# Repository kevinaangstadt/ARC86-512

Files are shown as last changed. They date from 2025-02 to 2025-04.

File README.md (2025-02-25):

# ARC86-512 Computer
## Introduction
This is a simple, but complete computer built around the 80C88 processor. In
addition to the processor, the computer has:
- 512KB of RAM
- 32KB of ROM
- 1 16C550 UART
- 1 8255 PIO
- 1 8253 PIT
- 1 8259 PIC
- CompactFlash interface
- 8Ω speaker
- 16x2 character LCD

## Hardware

Hardware designs are available in the `hardware` directory. The computer is
designed to be built on a breadboard.

The hardware is released under the [CERN Open Hardware Licence Version 2 - Permissive](hardware/LICENSE.txt).

## Software

Software is available in the `software` directory. The software is written in
assembly language and is designed to be built with the [NASM
assembler](https://www.nasm.us/).

C code is written to be compiled [Bruce's C Compiler
(bcc)](https://github.com/lkundrak/dev86).

The software is released under the [BSD 3-Clause License](software/LICENSE.txt).

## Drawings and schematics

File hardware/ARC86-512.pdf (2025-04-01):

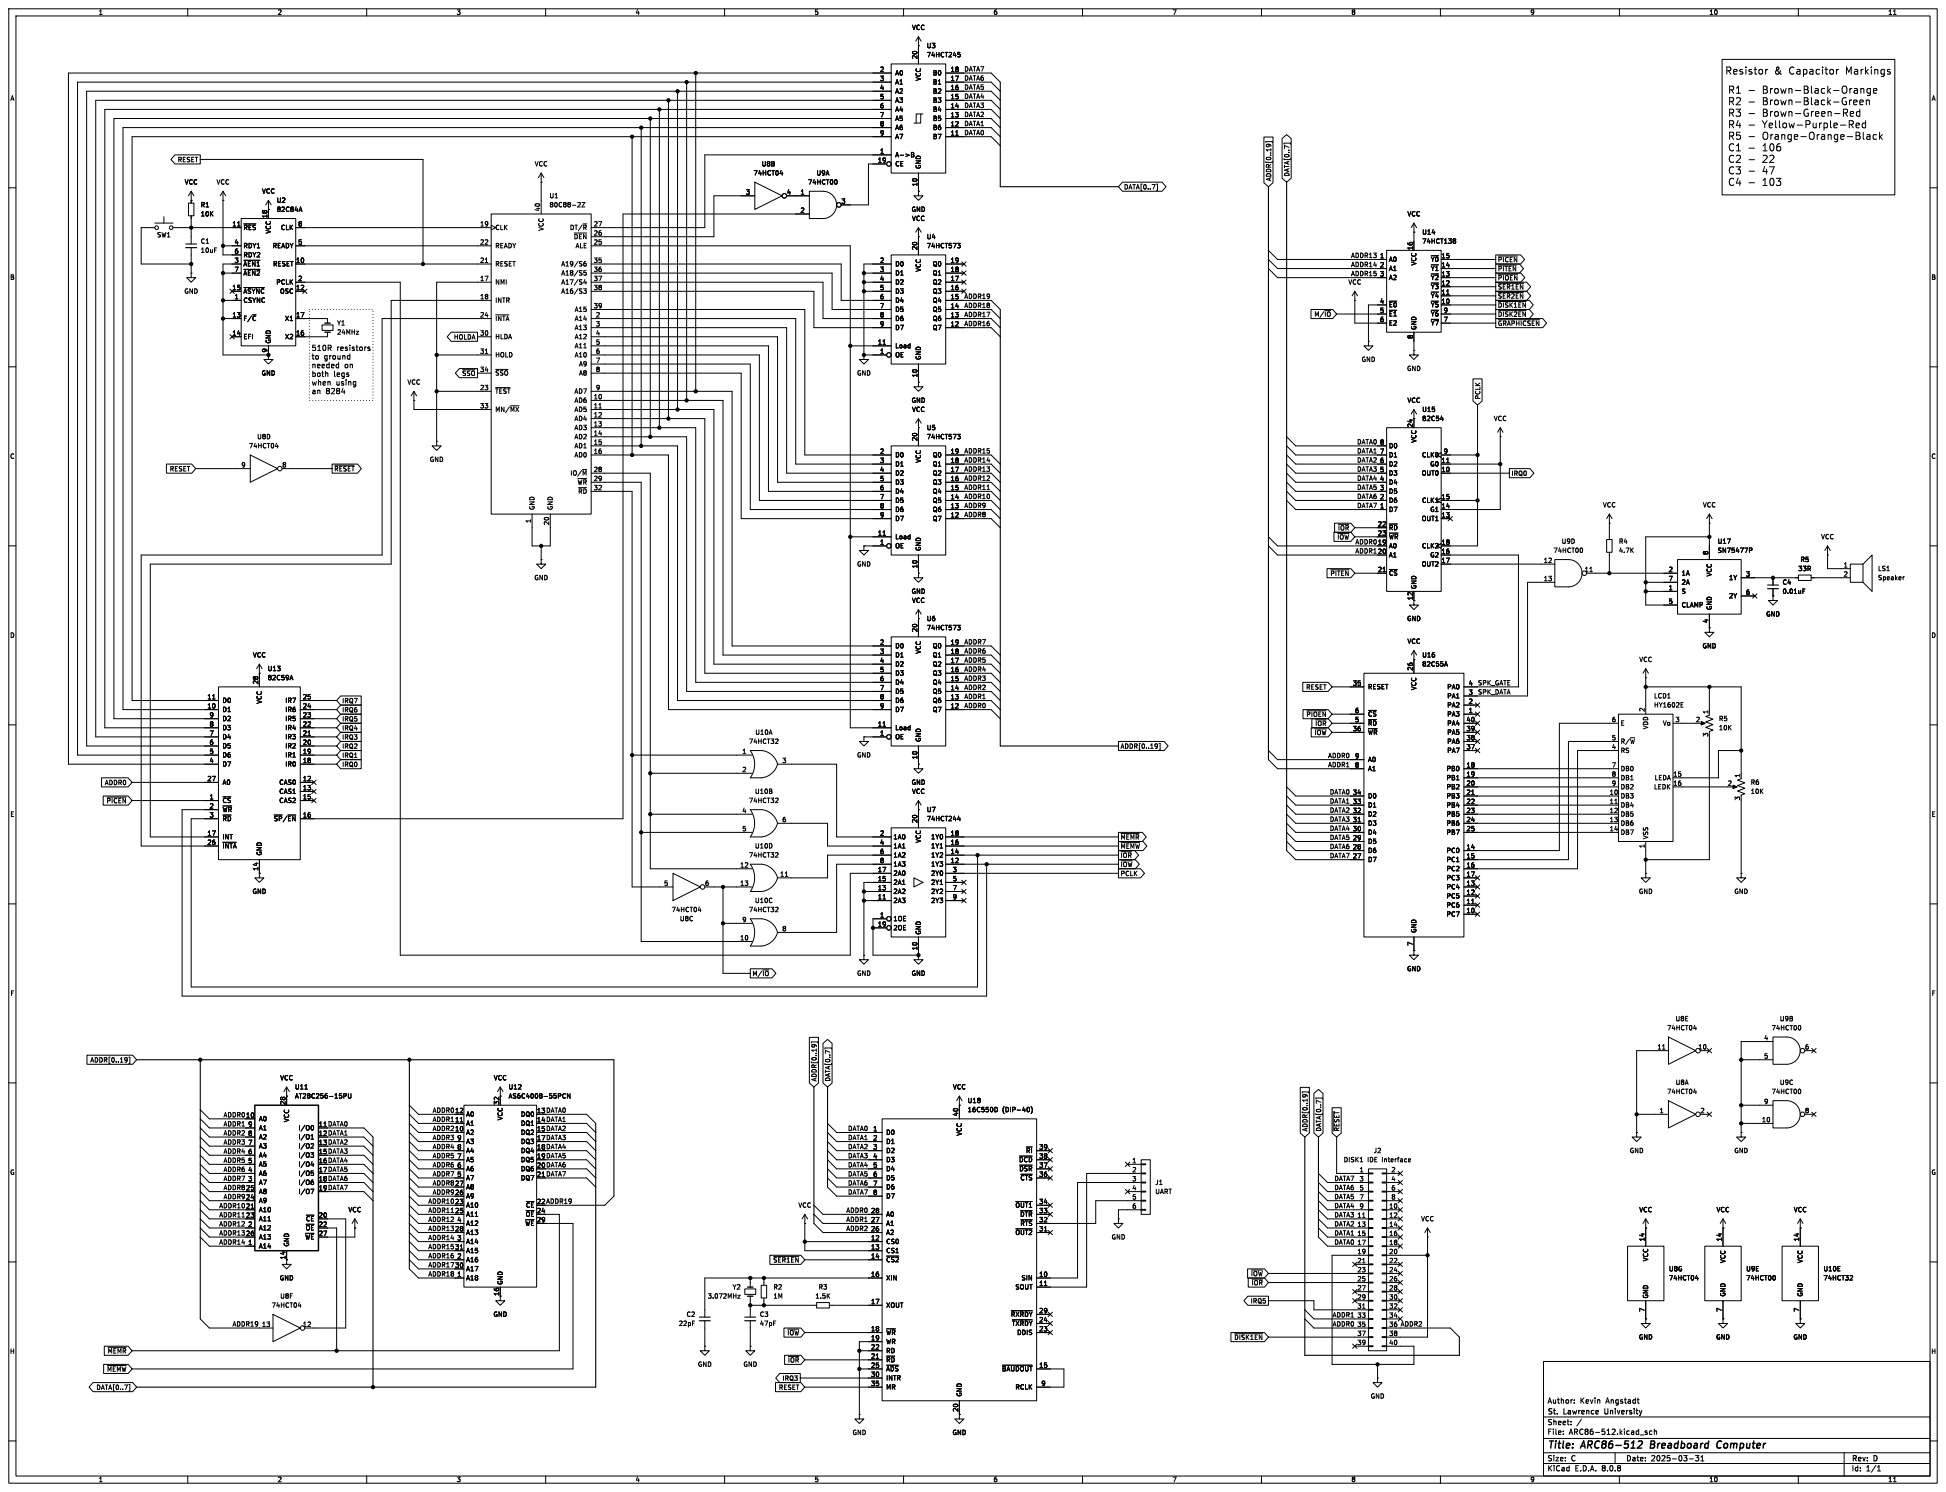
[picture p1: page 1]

510R resistors
to ground
needed on
both legs when using

ADDR[0..19] ~{MEMR} ~{MEMW} ~{IOW} PCLK

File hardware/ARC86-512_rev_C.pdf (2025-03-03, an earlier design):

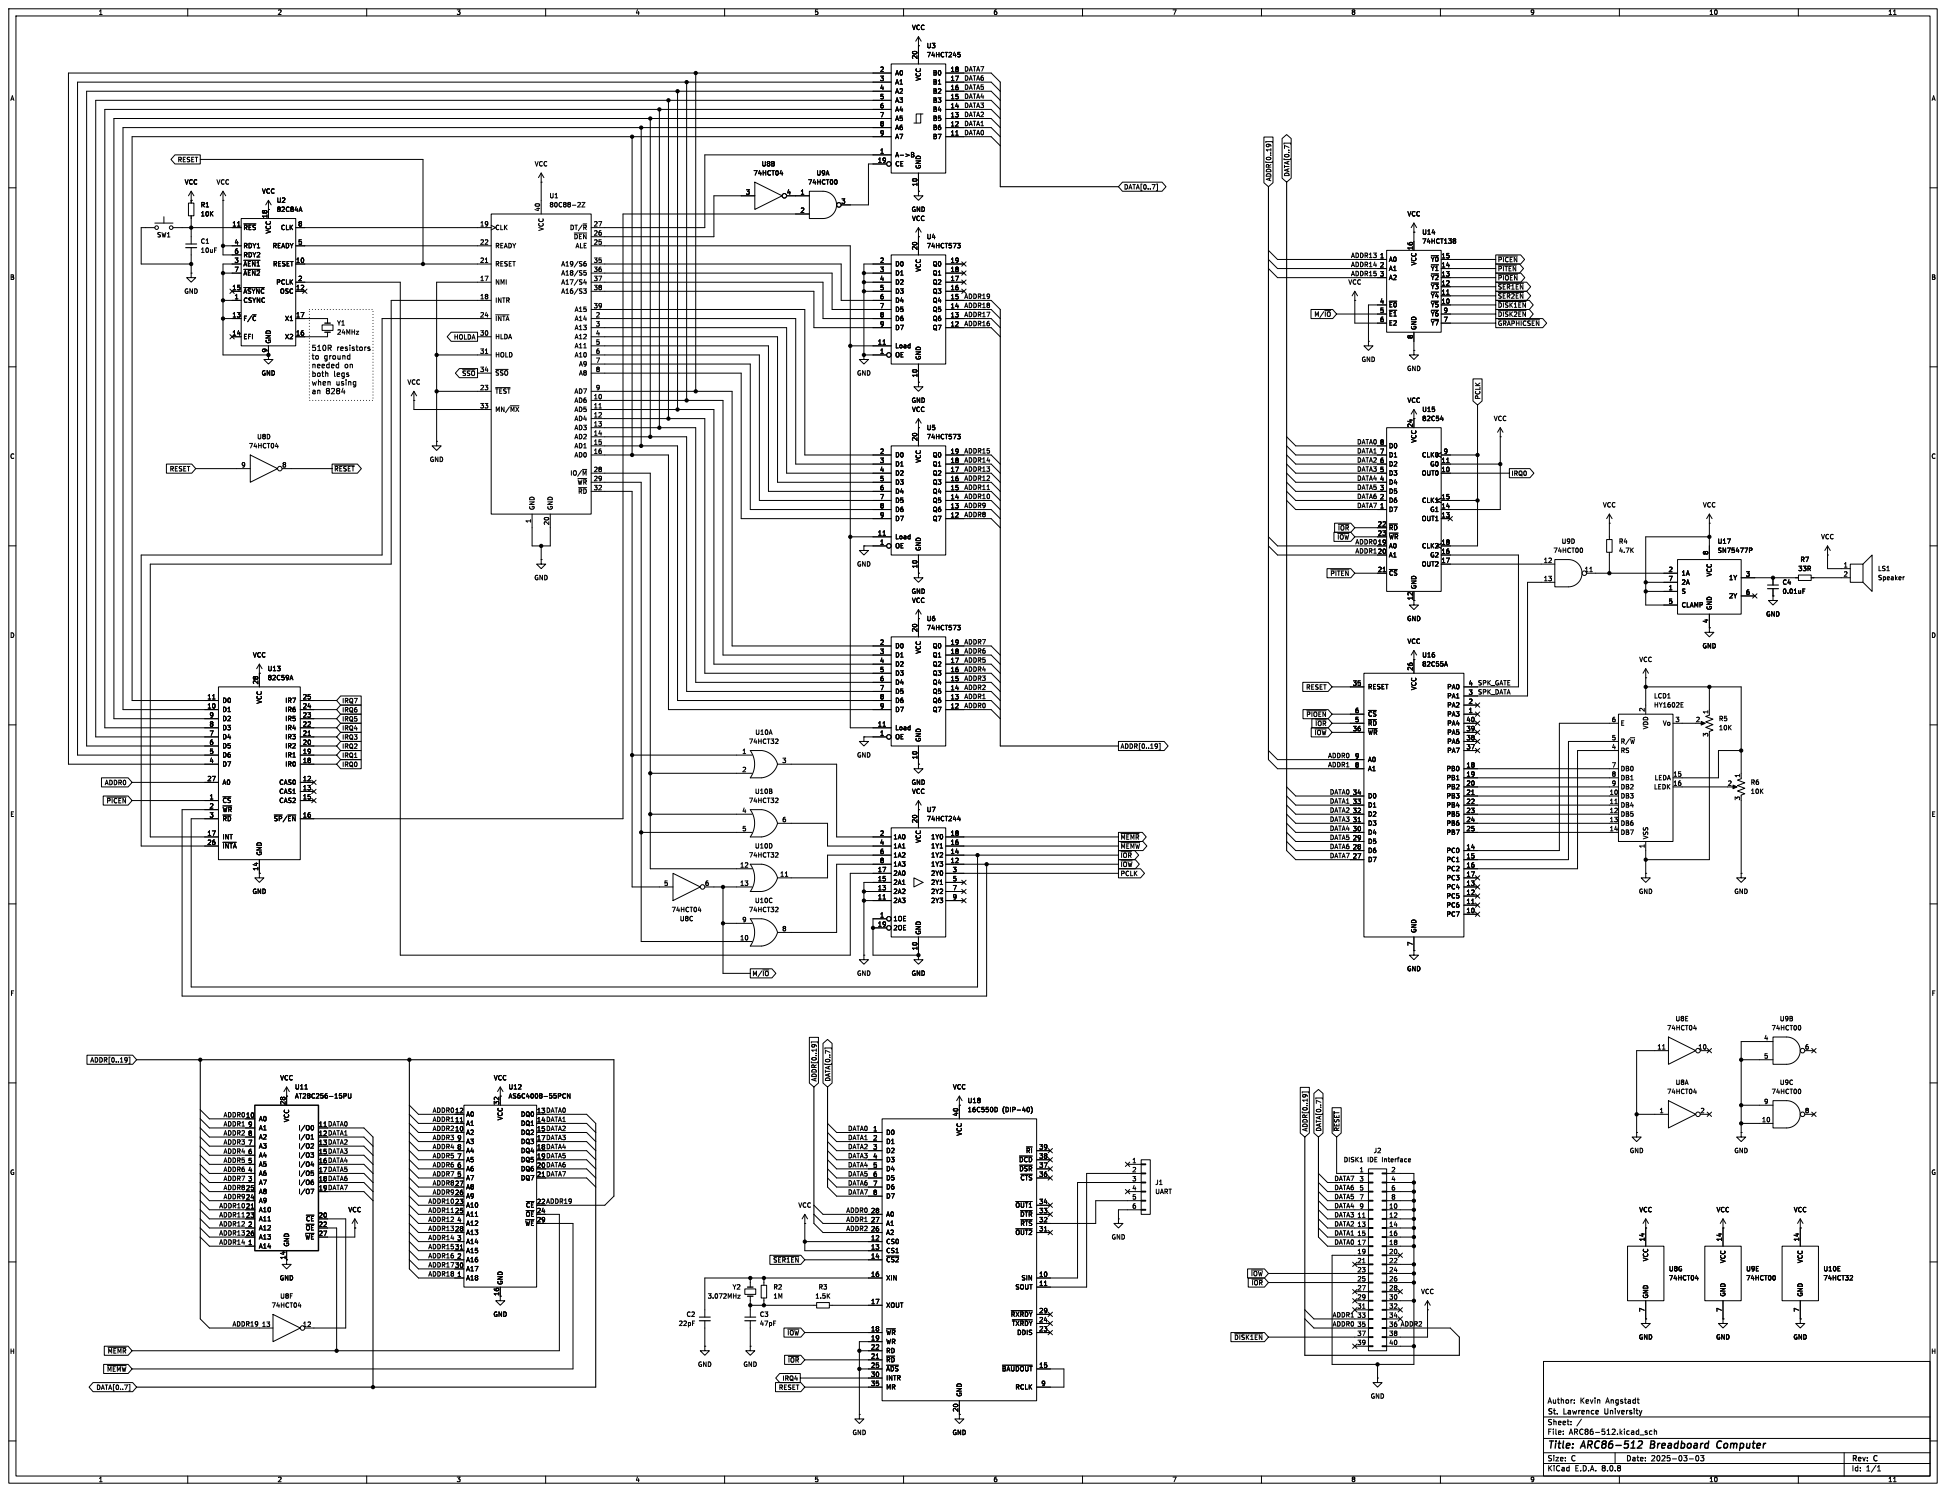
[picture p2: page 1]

~{SER2EN} ~{PITEN} ~{DISK2EN} ~{GRAPHICSEN} ~{SER1EN} ~{DISK1EN} ~{PICEN} ~{PIOEN} M/~{IO} ADDR[0..19] DATA[0..7]

~{IOW} ~{IOR} ~{PIOEN} RESET DATA[0..7]

~{MEMR} ~{IOR} ADDR[0..19] PCLK

74HCT04 VCC 14 GND 7 VCC GND

74HCT32 VCC 14 GND 7 VCC GND

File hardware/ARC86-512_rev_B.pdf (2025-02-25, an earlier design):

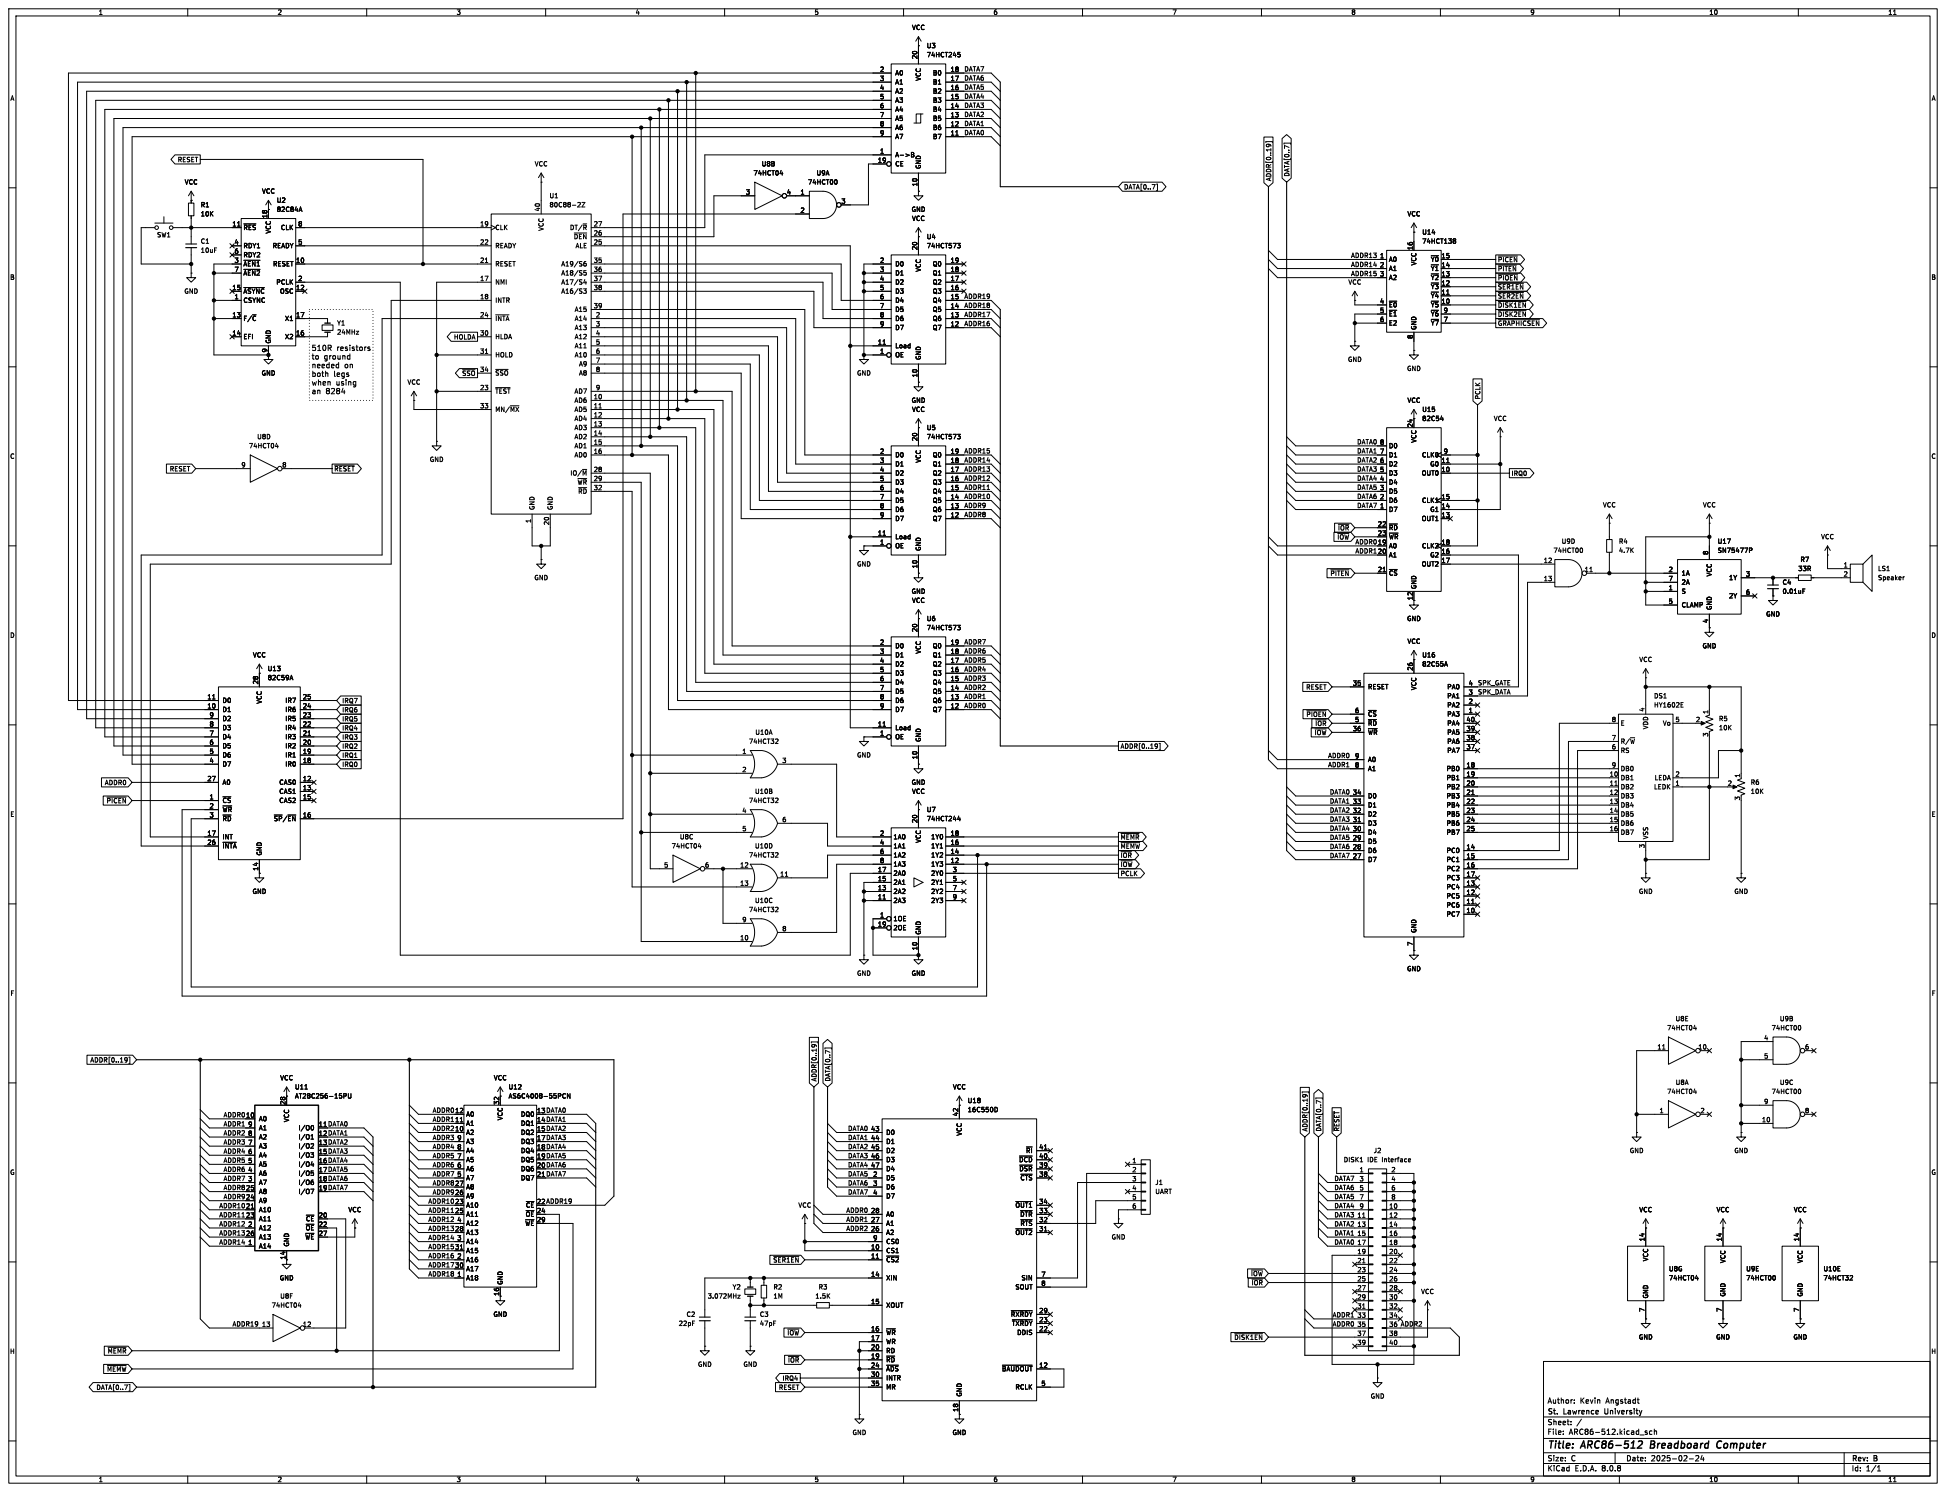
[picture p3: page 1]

to ground
needed on
both legs when using

~{PIOEN} ~{IOW} RESET ADDR[0..19] ~{IOR} ~{MEMW} ~{IOW} ~{MEMR}

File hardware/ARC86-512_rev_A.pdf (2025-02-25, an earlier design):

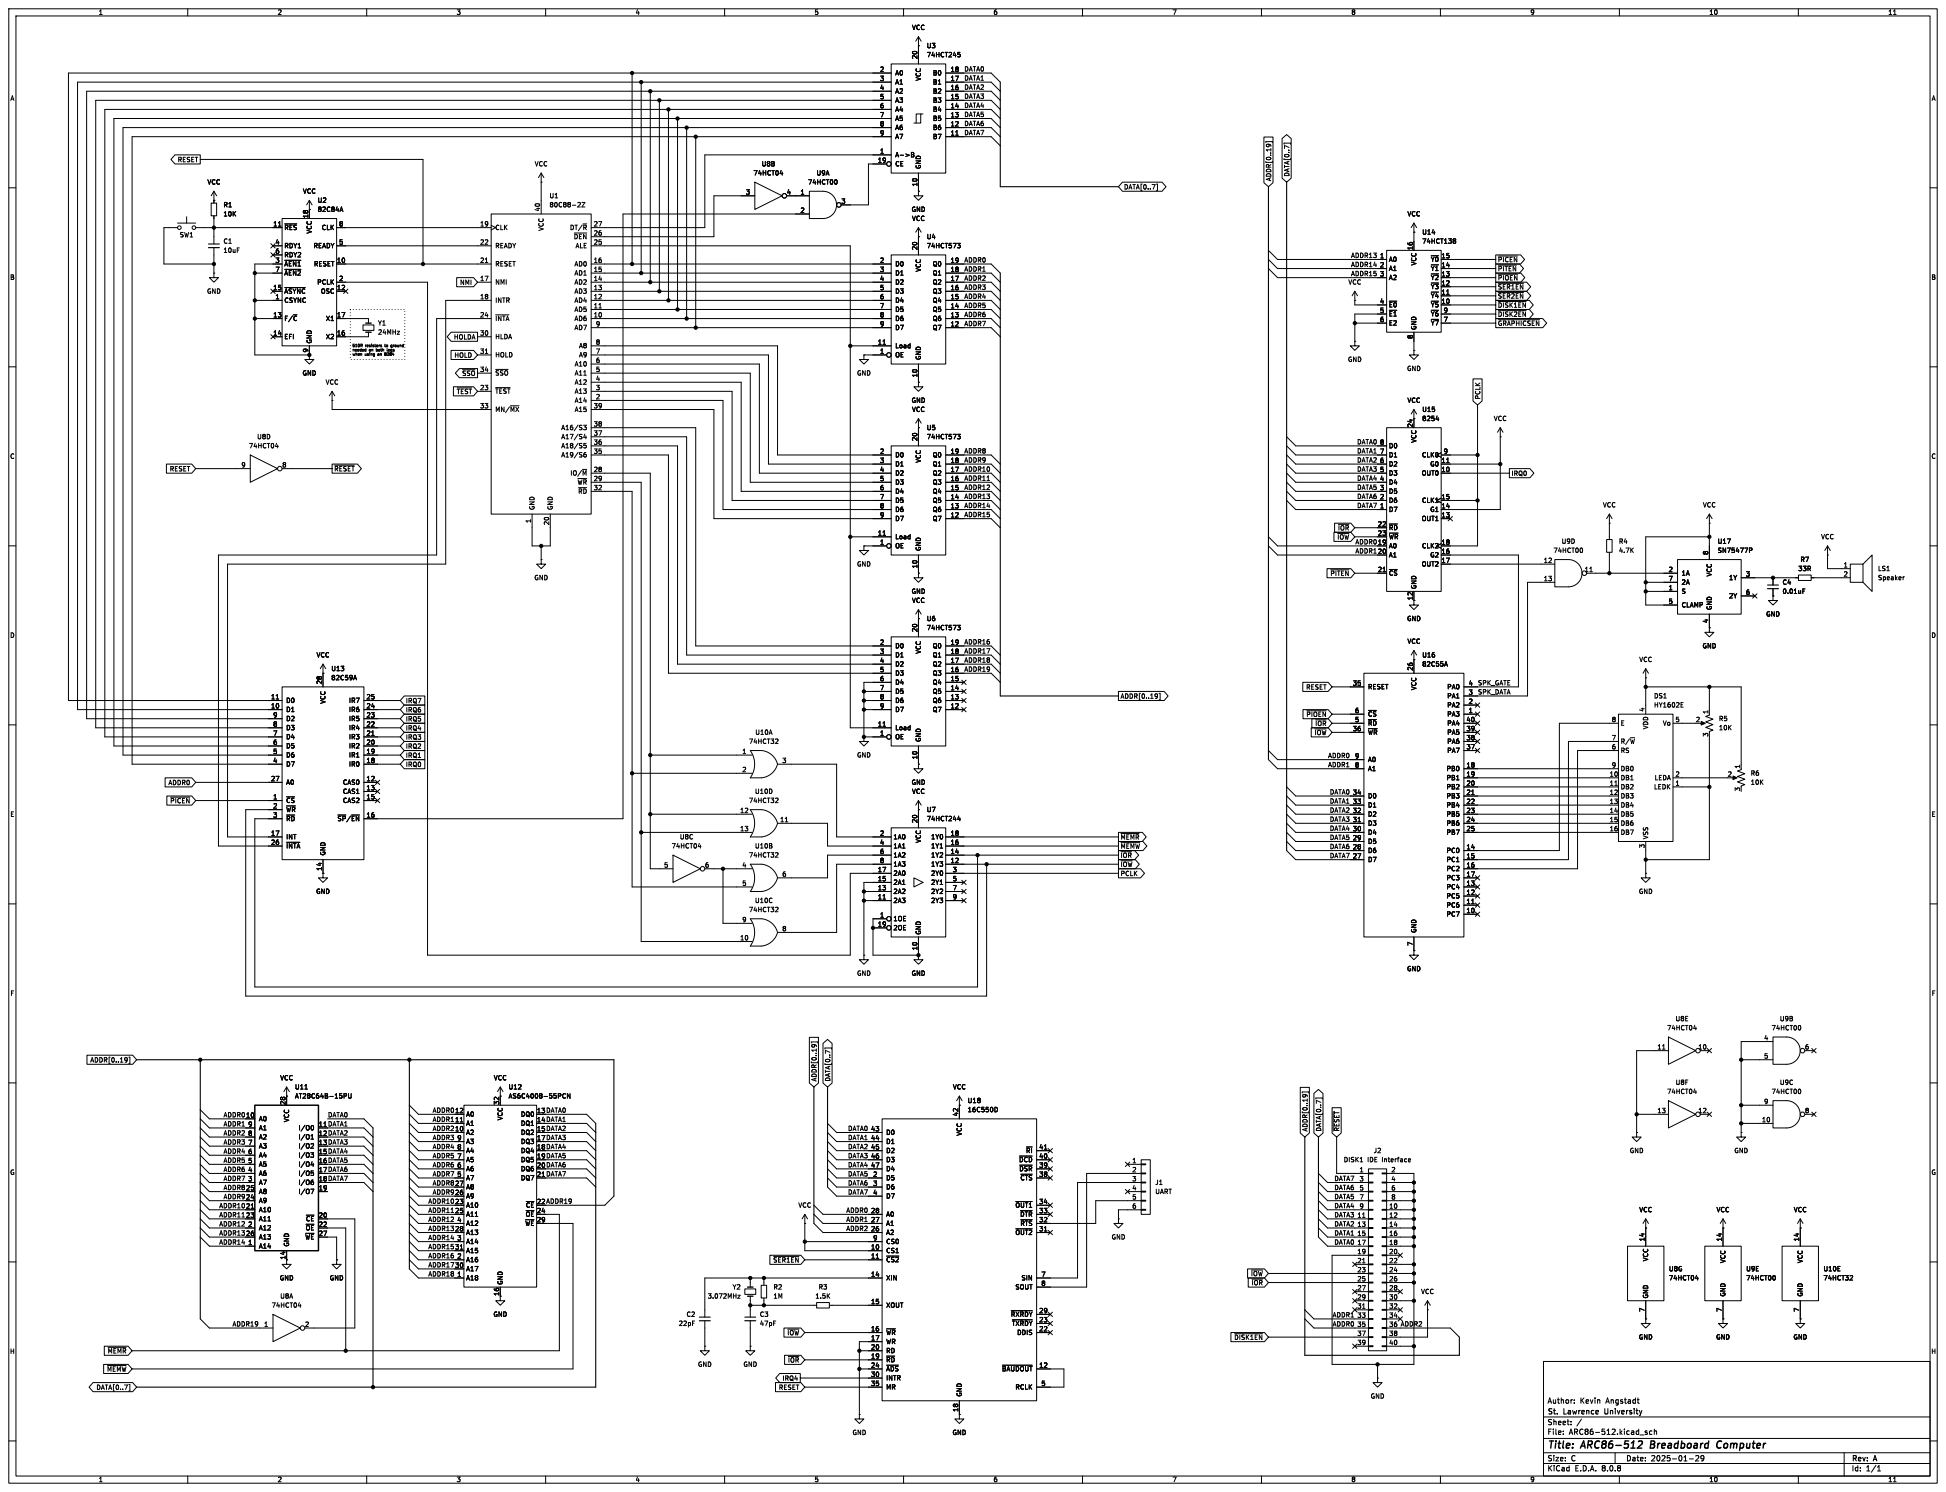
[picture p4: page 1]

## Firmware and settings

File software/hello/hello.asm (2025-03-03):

; set up the PIO Port B for output
; Configure the LCD for 8-bit mode

; NOTE: the PIO lives at IO port 0x4000
; address 0x00 PORT A
; address 0x01 PORT B
; address 0x02 PORT C
; address 0x03 Control Word

E equ 0x01
RS equ 0x04
RW equ 0x02

PORTA equ 0x4000
PORTB equ 0x4001
PORTC equ 0x4002
CTRL equ 0x4003

; the upper ROM chip starts at address 0xFE000
org 0xF8000

;;;;;;;;;;;;;;;;;;;;;;;;;;;;;;;;;;;;;;;;;;;;;;;;;;;;;;;;;;;;;;;;;;;;;;;;;;;;;;;;
; Initialize the LCD                                                           ;
;;;;;;;;;;;;;;;;;;;;;;;;;;;;;;;;;;;;;;;;;;;;;;;;;;;;;;;;;;;;;;;;;;;;;;;;;;;;;;;;

  ; set up GROUP A/B for MODE 0 output
  mov al, 0b10000000
  mov dx, CTRL
  out dx, al

  ; See the LCD datasheet for the initialization sequence
  ; Figure 23 on page 45 of the HD44780U datasheet for 8-Bit Interface Initialization

  ; busy wait for 40ms to allow the LCD to power up
  ; at 8Mhz, 1 cycle is 125ns meaning we need to busy wait for 320,000 cycles
  ; 320,000 cycles / 4 cycles per loop = 80,000 loops
  mov cx, 12000  ; 40000 loops
delay_loop1:
  nop            ; 4 cycle
  nop            ; 4 cycle
  nop            ; 4 cycle
  loop delay_loop1 ; 17 cycles to decrement and jump if not zero

  ; initialize with 8-bit mode with 3 commands 0x00110000
  mov al, 0b00110000
  mov dx, PORTB
  out dx, al
  ; clear RS/RW/E bits
  mov al, 0
  mov dx, PORTC
  out dx, al
  ; set E bit to send instruction
  mov al, E
  out dx, al
  ; clear RS/RW/E bits
  mov al, 0
  out dx, al

  ; wait for the LCD to process the instruction (more than 4.1ms)
  ; at 8Mhz, 1 cycle is 125ns meaning we need to busy wait for at least 32,800 cycles
  ; we will busy wait for 40,000 cycles
  mov cx, 1200  ; 10000 loops
delay_loop2:
  nop            ; 4 cycle
  nop            ; 4 cycle
  nop            ; 4 cycle
  loop delay_loop2 ; 17 cycles

  ; initialize a second time with 8-bit mode with 3 commands 0x00110000
  mov al, 0b00110000
  mov dx, PORTB
  out dx, al
  ; clear RS/RW/E bits
  mov al, 0
  mov dx, PORTC
  out dx, al
  ; set E bit to send instruction
  mov al, E
  out dx, al
  ; clear RS/RW/E bits
  mov al, 0
  out dx, al

  ; wait for the LCD to process the instruction (more than 100us)
  ; at 8Mhz, 1 cycle is 125ns meaning we need to busy wait for at least 800 cycles
  ; we will busy wait for 1000 cycles
  mov cx, 35    ; 34 loops
delay_loop3:
  nop            ; 4 cycle
  nop            ; 4 cycle
  nop            ; 4 cycle
  loop delay_loop3 ; 17 cycles

  ; initialize a third and final time time with 8-bit mode with 3 commands 0x00110000
  mov al, 0b00110000
  mov dx, PORTB
  out dx, al
  ; clear RS/RW/E bits
  mov al, 0
  mov dx, PORTC
  out dx, al
  ; set E bit to send instruction
  mov al, E
  out dx, al
  ; clear RS/RW/E bits
  mov al, 0
  out dx, al

  ; wait for the LCD to process the instruction
  ; set PORT B to input
  mov al, 0b10000010
  mov dx, CTRL
  out dx, al
wait6:
  mov al, RW
  mov dx, PORTC
  out dx, al
  ; set E bit to send instruction
  mov al, E | RW
  out dx, al
  ; read the busy flag
  mov dx, PORTB
  in al, dx
  and al, 0x80
  jne wait6
  mov al, 0
  mov dx, PORTC
  out dx, al
  ; set PORT B back to output
  mov al, 0b10000000
  mov dx, CTRL
  out dx, al

;;;;;;;;;;;;;;;;;;;;;;;;;;;;;;;;;;;;;;;;;;;;;;;;;;;;;;;;;;;;;;;;;;;;;;;;;;;;;;;;
; Set up the LCD with our desired settings                                     ;
;;;;;;;;;;;;;;;;;;;;;;;;;;;;;;;;;;;;;;;;;;;;;;;;;;;;;;;;;;;;;;;;;;;;;;;;;;;;;;;;
  ; set 8-bit mode; 2-line display; 5x8 font
  mov al, 0b00111000
  mov dx, PORTB
  out dx, al
  ; clear RS/RW/E bits
  mov al, 0
  mov dx, PORTC
  out dx, al
  ; set E bit to send instruction
  mov al, E
  out dx, al
  ; clear RS/RW/E bits
  mov al, 0
  out dx, al

  ; wait for the LCD to process the instruction
  ; set PORT B to input
  mov al, 0b10000010
  mov dx, CTRL
  out dx, al
wait1:
  mov al, RW
  mov dx, PORTC
  out dx, al
  ; set E bit to send instruction
  mov al, E | RW
  out dx, al
  ; read the busy flag
  mov dx, PORTB
  in al, dx
  and al, 0x80
  jne wait1
  mov al, 0
  mov dx, PORTC
  out dx, al
  ; set PORT B back to output
  mov al, 0b10000000
  mov dx, CTRL
  out dx, al

  ; display on; cursor on; blink off
  mov al, 0b00001110
  mov dx, PORTB
  out dx, al
  ; clear RS/RW/E bits
  mov al, 0
  mov dx, PORTC
  out dx, al
  ; set E bit to send instruction
  mov al, E
  out dx, al
  ; clear RS/RW/E bits
  mov al, 0
  out dx, al

  ; wait for the LCD to process the instruction
  ; set PORT B to input
  mov al, 0b10000010
  mov dx, CTRL
  out dx, al
wait2:
  mov al, RW
  mov dx, PORTC
  out dx, al
  ; set E bit to send instruction
  mov al, E | RW
  out dx, al
  ; read the busy flag
  mov dx, PORTB
  in al, dx
  and al, 0x80
  jne wait2
  mov al, 0
  mov dx, PORTC
  out dx, al
  ; set PORT B back to output
  mov al, 0b10000000
  mov dx, CTRL
  out dx, al

  ; increment and shift cursor; don't shift display
  mov al, 0b00000110
  mov dx, PORTB
  out dx, al
  ; clear RS/RW/E bits
  mov al, 0
  mov dx, PORTC
  out dx, al
  ; set E bit to send instruction
  mov al, E
  out dx, al
  ; clear RS/RW/E bits
  mov al, 0
  out dx, al

  ; wait for the LCD to process the instruction
  ; set PORT B to input
  mov al, 0b10000010
  mov dx, CTRL
  out dx, al
wait3:
  mov al, RW
  mov dx, PORTC
  out dx, al
  ; set E bit to send instruction
  mov al, E | RW
  out dx, al
  ; read the busy flag
  mov dx, PORTB
  in al, dx
  and al, 0x80
  jne wait3
  mov al, 0
  mov dx, PORTC
  out dx, al
  ; set PORT B back to output
  mov al, 0b10000000
  mov dx, CTRL
  out dx, al

  ; Clear display
  mov al, 0b00000001
  mov dx, PORTB
  out dx, al
  ; clear RS/RW/E bits
  mov al, 0
  mov dx, PORTC
  out dx, al
  ; set E bit to send instruction
  mov al, E
  out dx, al
  ; clear RS/RW/E bits
  mov al, 0
  out dx, al

  ; wait for the LCD to process the instruction
  ; set PORT B to input
  mov al, 0b10000010
  mov dx, CTRL
  out dx, al
wait4:
  mov al, RW
  mov dx, PORTC
  out dx, al
  ; set E bit to send instruction
  mov al, E | RW
  out dx, al
  ; read the busy flag
  mov dx, PORTB
  in al, dx
  and al, 0x80
  jne wait4
  mov al, 0
  mov dx, PORTC
  out dx, al
  ; set PORT B back to output
  mov al, 0b10000000
  mov dx, CTRL
  out dx, al

  ; pause for about a bit
  mov cx, 0xffff  ; 65536 loops
delay_loop4:
  nop            ; 4 cycle
  nop            ; 4 cycle
  nop            ; 4 cycle
  loop delay_loop4 ; 17 cycles
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

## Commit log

2025-03-02 Tests for address wiring on ROM
2025-03-03 REVC of schematic
    [ARC86-512.kicad_sch]
2025-04-01 Rev D of schematic
    [ARC86-512.kicad_sch]
